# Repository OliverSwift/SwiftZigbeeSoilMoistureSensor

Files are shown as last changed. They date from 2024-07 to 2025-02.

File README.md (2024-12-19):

# Swift Zigbee Soil Moisture Sensor

This hardware project is about creating a Zigbee adapter to the existing Capacitive Soil Moisture Sensor 1.2 widely available.

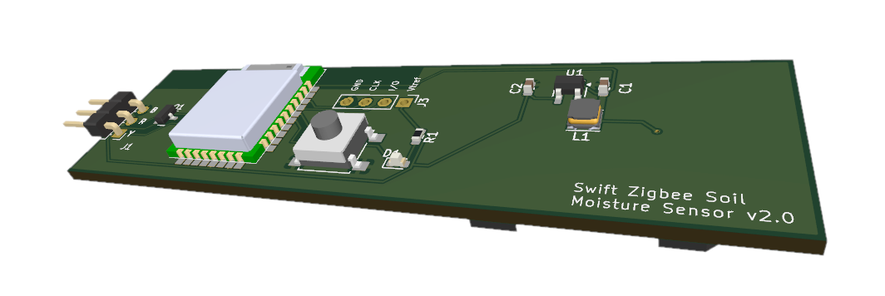
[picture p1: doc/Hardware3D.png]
Hw illustration Hardware


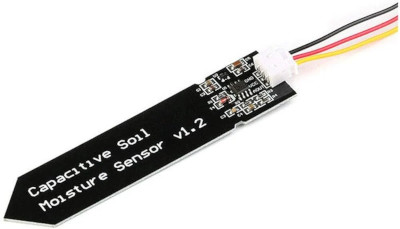
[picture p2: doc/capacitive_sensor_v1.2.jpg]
Capacitive Sensor


## How to use it

[Here is](doc/Swift%20Zigbee%20Soil%20Moisture%20Sensor.pdf) the small user manual.

It works well with Conbee2 and SONOFF zigbee concentrators used with Home Assistant.

CR2032 coin battery should allow approximately two years of autonomy.

## Technical background

After some trials on STM32WB55 which permanently failed to connect to a zigbee concentrator (Conbee2) I finally chose the nrf52840 SOC from Nordic Semicondudtors. It is very well known in the BLE world and decided to test its Zigbee capabilities and it was successful. Best solutions are provided by Texas Instrument (CC2350) and Silabs (EFR32MG1) at the moment. Using nrf52840 for Zigbee is the challenge here.

The solution is based on ZephyrOS and NRF Connect SDK version 2.6.1 that includes ZBoss proprietary Zigbee stack. One of the challenging aspect of this project is the power consumption. The nrf52840 is able to enter deep sleep and only consumes 2.5µA approximately. Now I had to face that the Capacitive Sensor is based on a NE555. Surprisingly it is not the CMOS version and is supposed to be power supplied between 5 and 15V. But it can be with only 3.3V. Any attempt to power supply below this value resulted in unstable sensor. So I decided to use 3.3V for the whole device (MCU+sensor). This led to choosing a boost converter so a coin battery can be used, ideally CR2032.

The average current measurement is about 10µA, which should allow 2 year autonomy. Probe measurement is done every 30 minutes. When it occurs, the tiny LED lits.

The project was developed thanks to [nRF52840 DK board](doc/nRF52840_DK_User_Guide_v1.2.pdf). I used the OB JLink capability to flash the target board.

The nRF52840 module (E73-2G4M08S1C) comes from EBYTE. It doesn't have the external 32kHz crystal, but this one isn't useful for Zigbee applications.

Documentation folder includes:

- [Electronic schematics](doc/schematics-2.0.pdf)
- Main components datasheet (nrf52840 and tps61097a)
- [How to build and flash](doc/how_to_compile.md)

CAD folder includes:

- [KiCAD](cad/KiCAD) project files
- [FreeCAD](cad/FreeCAD) projet, a desparate attempt to design a [box with a lid](cad/FreeCAD/box+lid.stl).

## Project details

### Building system

The ZephyrOS ecosystem provides high level build system called _west_. It's a pile of Python scripts that doesn't do much else than invoking _cmake_. I quickly realized that cmake can be used solely without the cumbersome _west_ layer. I ended up with a simple Makefile to achieve the bare necessities. 

Forgot to say that I use Linux (Ubuntu or Debian), but this should work well with MacOSX either. I struggled to make Nordic tools to run on Ubuntu 24.04 (app images need to run without sandbox), but this is definitely possible.

Before compiling, ensure to run shell that sets environment variables properly. This tiny shell can be generated by SDK Management Tool.

Building for target is building for production. Use make _clean_, _prod_ and _flash_prod_ for final hardware.

Building for developement on DK is done with a simple 'make' and 'make flash'. In this configuration, serial line is used for message printing and measurement is performed every minute (see _prj.conf_ file).

### Zigbee part

Since it's a soil moisture sensor the device exposes a standard profile from ZHA. I added the battery profile to monitor the coin battery health. These two profiles are installed in main.c file. I crafted a derived battery profile structure myself (ZB_ZCL_DECLARE_POWER_CONFIG_ATTRIB_LIST2), because the predefined ones were either thick or missing additional definitions. Some missing stuff in ZBoss library. Since these structures are built with macros, it wasn't hard to build a more suitable one.

The device is a **Sleepy End Device** (SED), so it doesn't contribute to Zigbee network activities, it just reports periodically attributes.
Low power management was actually easy to do, the nrf52840 is very convenient for this. Choose the SDK wisely, the one that actually worked well for low power is SDK 2.6.1. Older ones resulted in 700µA consumption while asleep. This was way too far from promising 2µA or so. With SDK 2.6.1 the module only consumes 2.3µA when entering deep sleep.

Setting up a SED consists in calling '_zigbee_configure_sleepy_behavior(true)_' and '_power_down_unused_ram()_' at start up. The project configuration file (prj_power_saving.conf) contains:
- CONFIG_ZIGBEE_ROLE_END_DEVICE=y
- CONFIG_RAM_POWER_DOWN_LIBRARY=y

directives for that purpose.

The most tricky part of the code lies in Zigbee event management especially when joining or leaving a network. It also deals with factory reset.

Long poll interval is adjusted to 2 minutes instead of default 7 seconds. This drastically reduces average consumption. More than 2 minutes resulted in rejoin procedure failure or reparenting failure in the mesh. That caused headaches. My opinion is that this part is the weak one of ZBoss stack (also used with ESP32 systems). That's where Silabs and Texas Instrument are still leading the Zigbee field.

### I/O

Two analog inputs are setup, one for probe and one to measure battery voltage. Due to E73 module pinout, peculiar pins were chosen so they are accessible among the castellated ones.

The probe uses 10mA to make a humidity measurement. So it is driven by a MOSFET controlled by a GPIO. The probe is therefore powered when used. A serie of measurements are done in a loop until stable.

A led is useful with embedded devices. The one on this board reflects pairing process status and measurement operation.

As mentioned, the 32kHz external crystal is not used, saving some components. It is not needed for Zigbee because clock precision isn't required here. But, it is necessary to add the two following defines in project file:
- CONFIG_CLOCK_CONTROL_NRF_K32SRC_RC=y
- CONFIG_CLOCK_CONTROL_NRF_K32SRC_XTAL=n

This tells bootloader not to use internal 32kHz clock and not to calibrate it. Otherwise MCU won't boot stuck in calibration loop.

Using the internal 32kHz clock didn't result in extra consumption.

### Hardware part

As mentionned earlier, the external probe needs at least 3.3V. The nrf52840 usually runs at 3V (usual coin battery voltage), but supports up to 3.7V. I had to find a boost IC with low quiescent current so I can use a 3V battery and power supplies the external probe. Best choice so far is a TPS 61097a from Texas Instrument (TPS 61121 worked well either, but was twice as much more expensive).

### Measurement

The measurement operation occurs every 30 minutes. This is configured in _Kconfig_ file. An hour should suffice actually and save more power.

A low filter is applied on subsequent measures. It might be too strong and should be reduced.

Illustration of using _Swift Soil Moisture Sensor_ in Home Assistant:

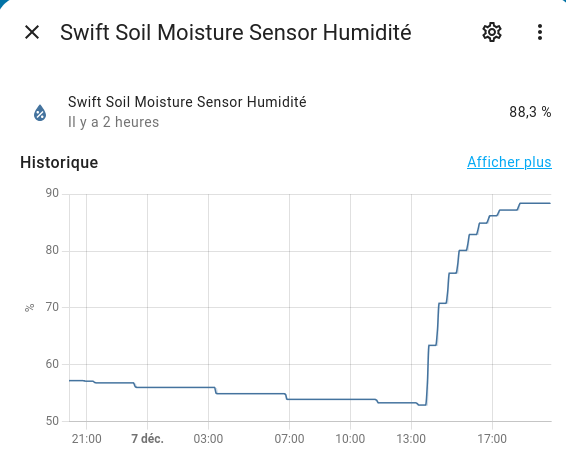
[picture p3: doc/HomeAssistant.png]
HomeAssistant


## LICENSE

SPDX-License-Identifier: AGPL-3.0-or-later

[GNU AFFERO GENERAL PUBLIC LICENSE, Version 3, 19 November 2007](LICENSE)

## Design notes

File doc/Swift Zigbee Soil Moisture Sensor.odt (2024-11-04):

Swift Zigbee Soil Moisture Sensor

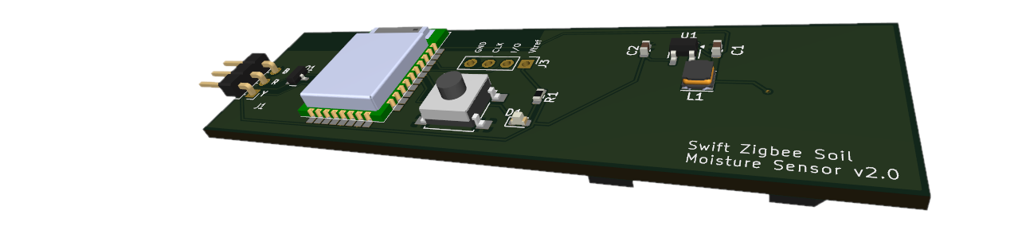
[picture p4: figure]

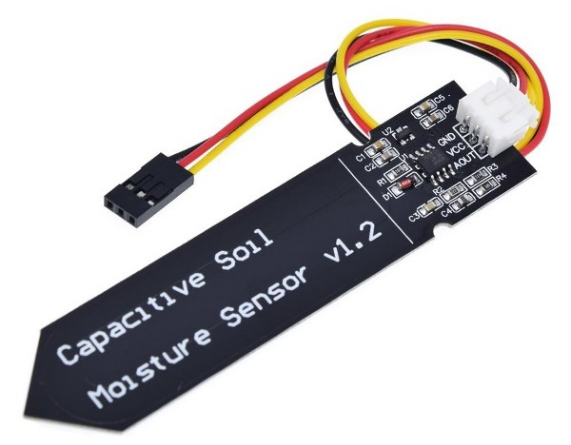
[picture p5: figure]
Capacitive soil moisture sensor V1.2 – ielectrony
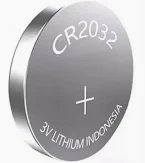
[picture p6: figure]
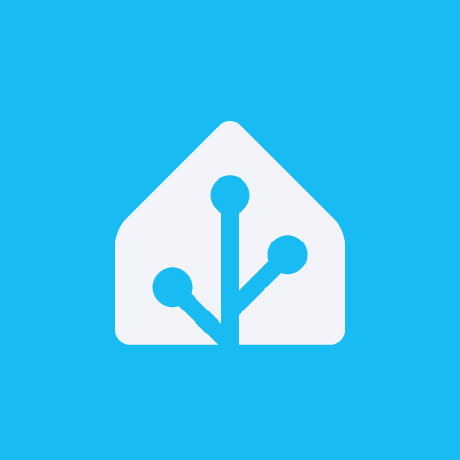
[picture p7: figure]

Needed accessories: CR2032 battery cell Capacitive Soil Moisture Sensor v1.2 Any Zigbee 3.0 ZHA compatible hub

# Prepare board

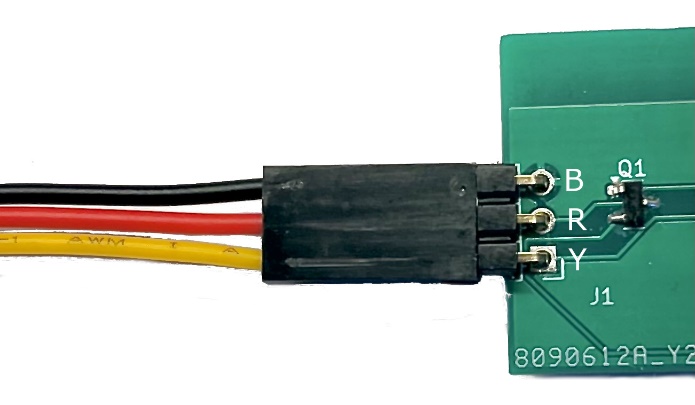
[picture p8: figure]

Connect sensor to board using its cable. The black wire must be connected to the pin B of the Zigbee adapter:

# First Pairing

Start your Zigbee Coordinator (Home Assistant for example) and launch pairing operation.

Place Zigbee board near to your coordinator device (approximately a meter away). Insert coin cell battery promptly into the battery socket located at the back of the Zigbee board.

The LED starts to blink on the Zigbee board. Twice per second. Once it has paired with coordinator LED stops blinking. It will lit every 30 minutes when measurement occurs.

Place the whole device where you want to use it.

# Factory reset

Remove coin cell battery. Press SW1 button WHILE inserting the battery back into the socket. LED will blink rapidly. Release the button. Device resets and LED starts to blink again for pairing.

# Trouble shooting

In case of values updated as “unknown” or connection loss, just remove and re-insert coin battery. Check sensor connection.

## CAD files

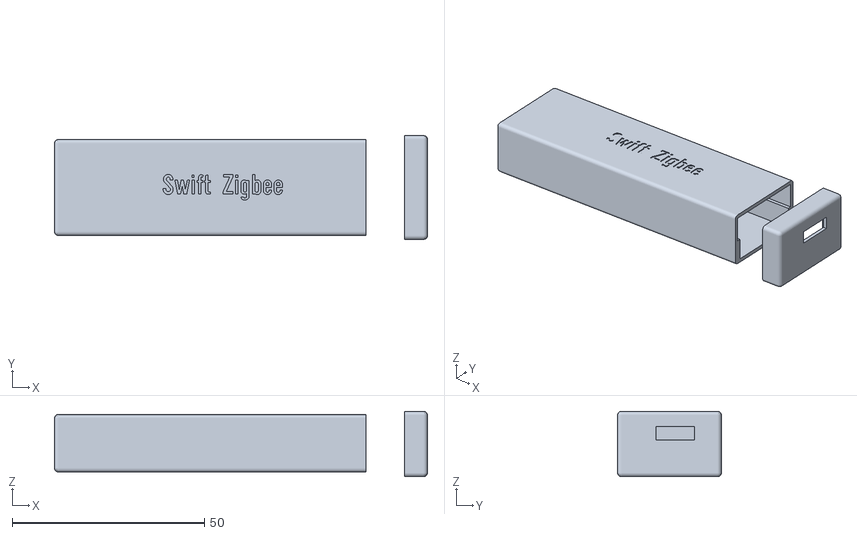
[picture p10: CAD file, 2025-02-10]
cad/FreeCAD/box+lid.stl
97.0 x 27.0 x 17.0

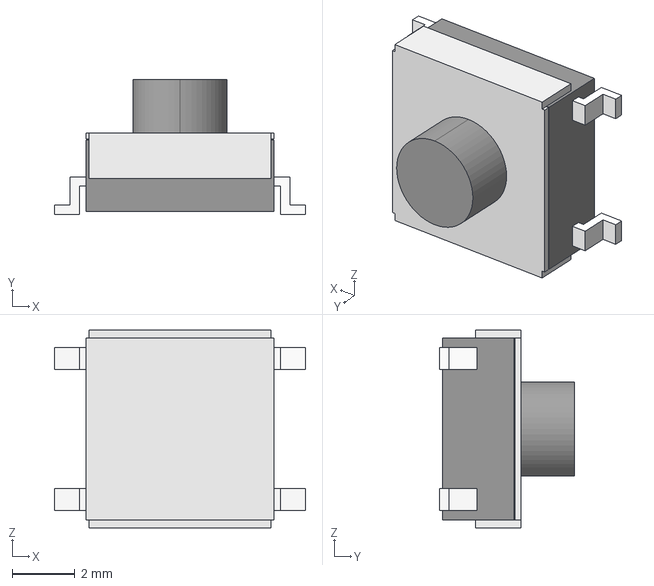
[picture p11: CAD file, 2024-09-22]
cad/KiCAD/B3FS-1010/B3FS-1010.STEP
8.00 x 4.30 x 6.30 mm

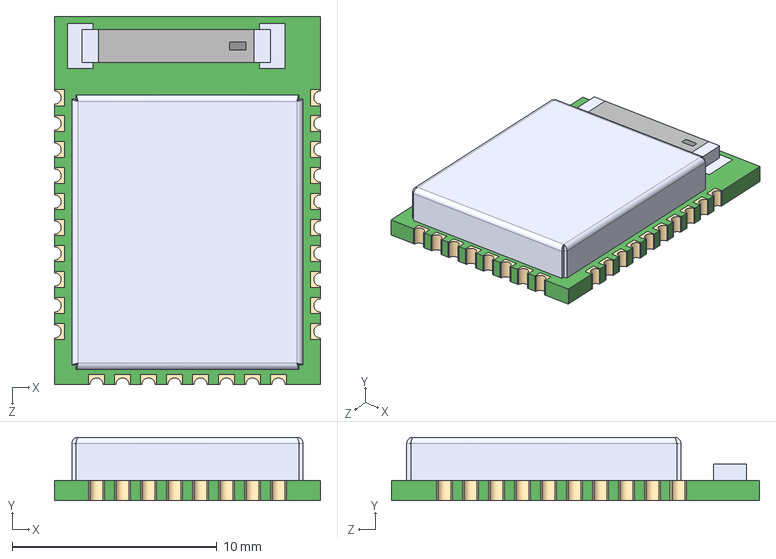
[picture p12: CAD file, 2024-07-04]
cad/KiCAD/E73-2G4M08S1C/E73-2G4M08S1C.step
13.0 x 3.10 x 18.0 mm

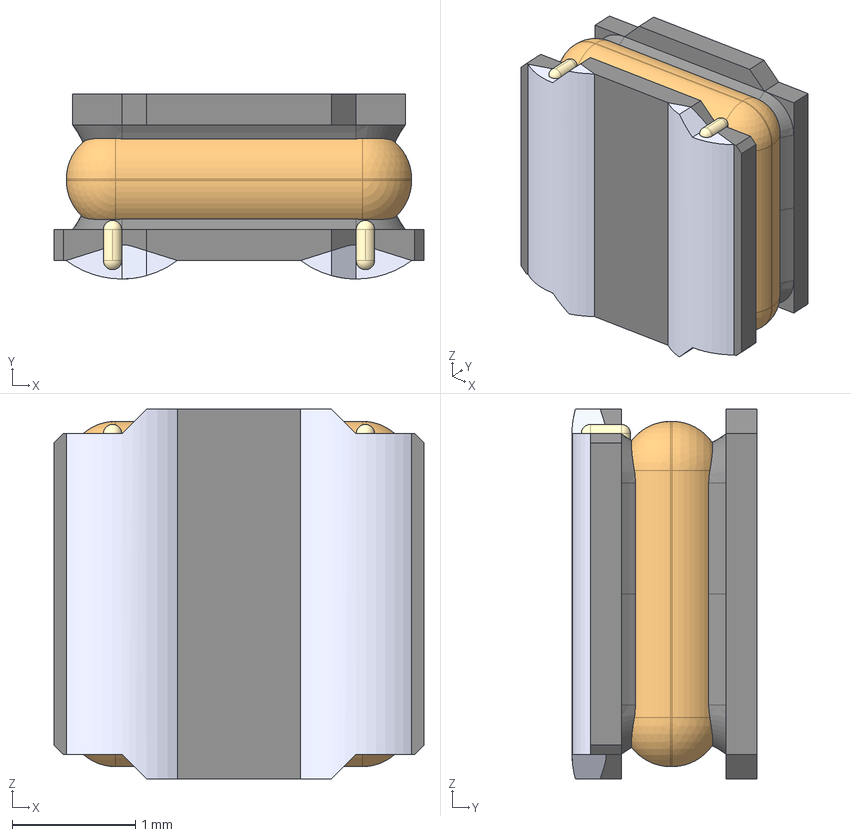
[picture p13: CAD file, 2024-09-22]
cad/KiCAD/NR3015T4R7M/NR3015T4R7M.stp
3.00 x 1.50 x 3.00 mm
NR3015T4R7M x 2
NR3015T4R7M001 x 2
NR3015T4R7M002 x 2
NR3015T4R7M003 x 2
NR3015T4R7M004 x 2
NR3015T4R7M005 x 2
NR3015T4R7M006 x 2

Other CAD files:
cad/FreeCAD/box.FCStd

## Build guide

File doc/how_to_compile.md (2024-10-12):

# With nRF Connect for Desktop
1. Get [nRF Connect for Desktop](https://www.nordicsemi.com/Products/Development-tools/nrf-connect-for-desktop)
2. Start it.
3. Install Toolchain Manager.
4. Launch Toolchain Manager (Click the Open button)
5. Install nRF Connect SDK 2.6.1 (only valid version for low power)
6. From the dropdown list select Generate Environment Script, save it to ~/ncs for example

~/ncs is where everything stands

Tools for flashing are required, see below nrf Command line Tools.

## Installing SDK Manually

Not recommanded but used SDK may not be available from nRF Connect for Desktop later on.

[Here](https://developer.nordicsemi.com/nRF_Connect_SDK/doc/latest/nrf/installation/install_ncs.html)

## Compile the project

Make sure you source the env.sh script that sets up SDK environment variables

then type:

```
# make
```

## Compile for production

```
# make clean
# make prod
```

## Nordic's page

Source pages about installations:  [SDK Installation ](https://developer.nordicsemi.com/nRF_Connect_SDK/doc/latest/nrf/installation.html)

# Installing nrfjprog for flashing

## Install nrf-Command-Line-Tools

Download [here](https://www.nordicsemi.com/Products/Development-tools/nrf-command-line-tools)

```
# dpkg -i nrf-command-line-tools_10.24.0_amd64.deb
```

Last output lines propose to install JLink that comes with the package. This is the preferred way.

## SEGGER JLink installation [optional]

Install above should propose to install JLink which is recommended.

However, it may also be installed manually:

We need to install SEGGER JLink took first. Visit [SEGGER's download page](https://www.segger.com/downloads/jlink)
And install Linux version.

```
# dpkg -i JLink_Linux_V794i_x86_64.deb
```

# Flashing the device

The board J3 connector pins have Vtref, SWDIO, SWDCLK and GND. The three should be properly wired to any SWD compatible
programming device (JLink, OB-Jlink, etc).

Cell coin battery MUST NOT be inserted during flashing operation.

## Using nrf52840 DK board for flashing

The PCA10056 comes with SEGGER J-Link OB with a debug out option.
Here is how to wire the DK to board for flashing:

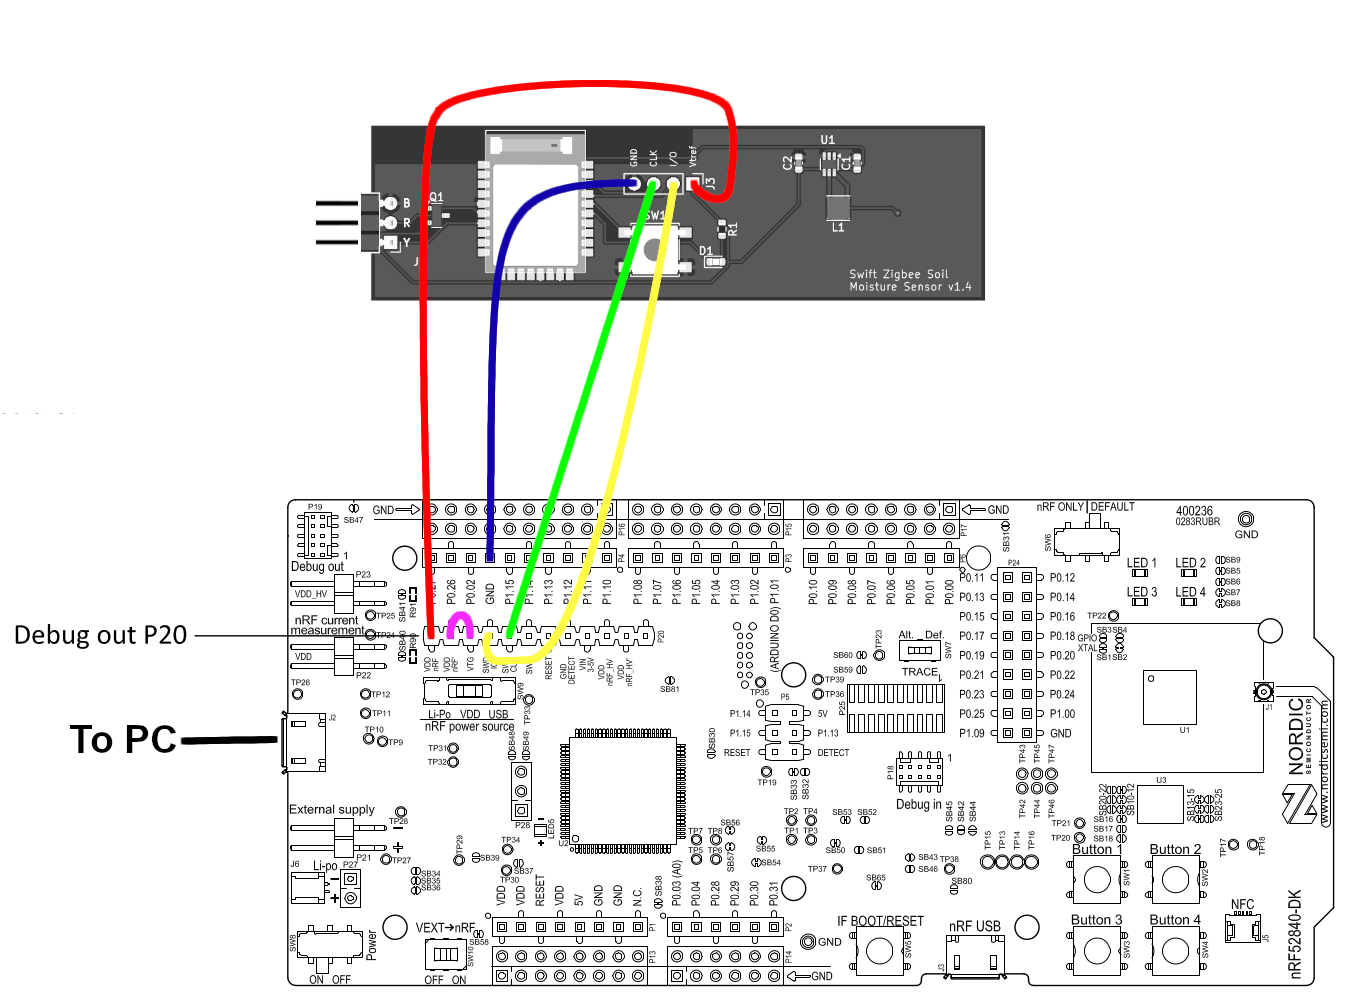
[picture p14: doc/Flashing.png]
Flashing


## Flash for dev

With JLink Probe attached to PC and board type:

```
# make flash
```

## Flash for production

Warning: AP protection is applied here. No possible debug or memory readback possible after this.

With JLink Probe attached to PC and board type:

```
# make flash_prod
```

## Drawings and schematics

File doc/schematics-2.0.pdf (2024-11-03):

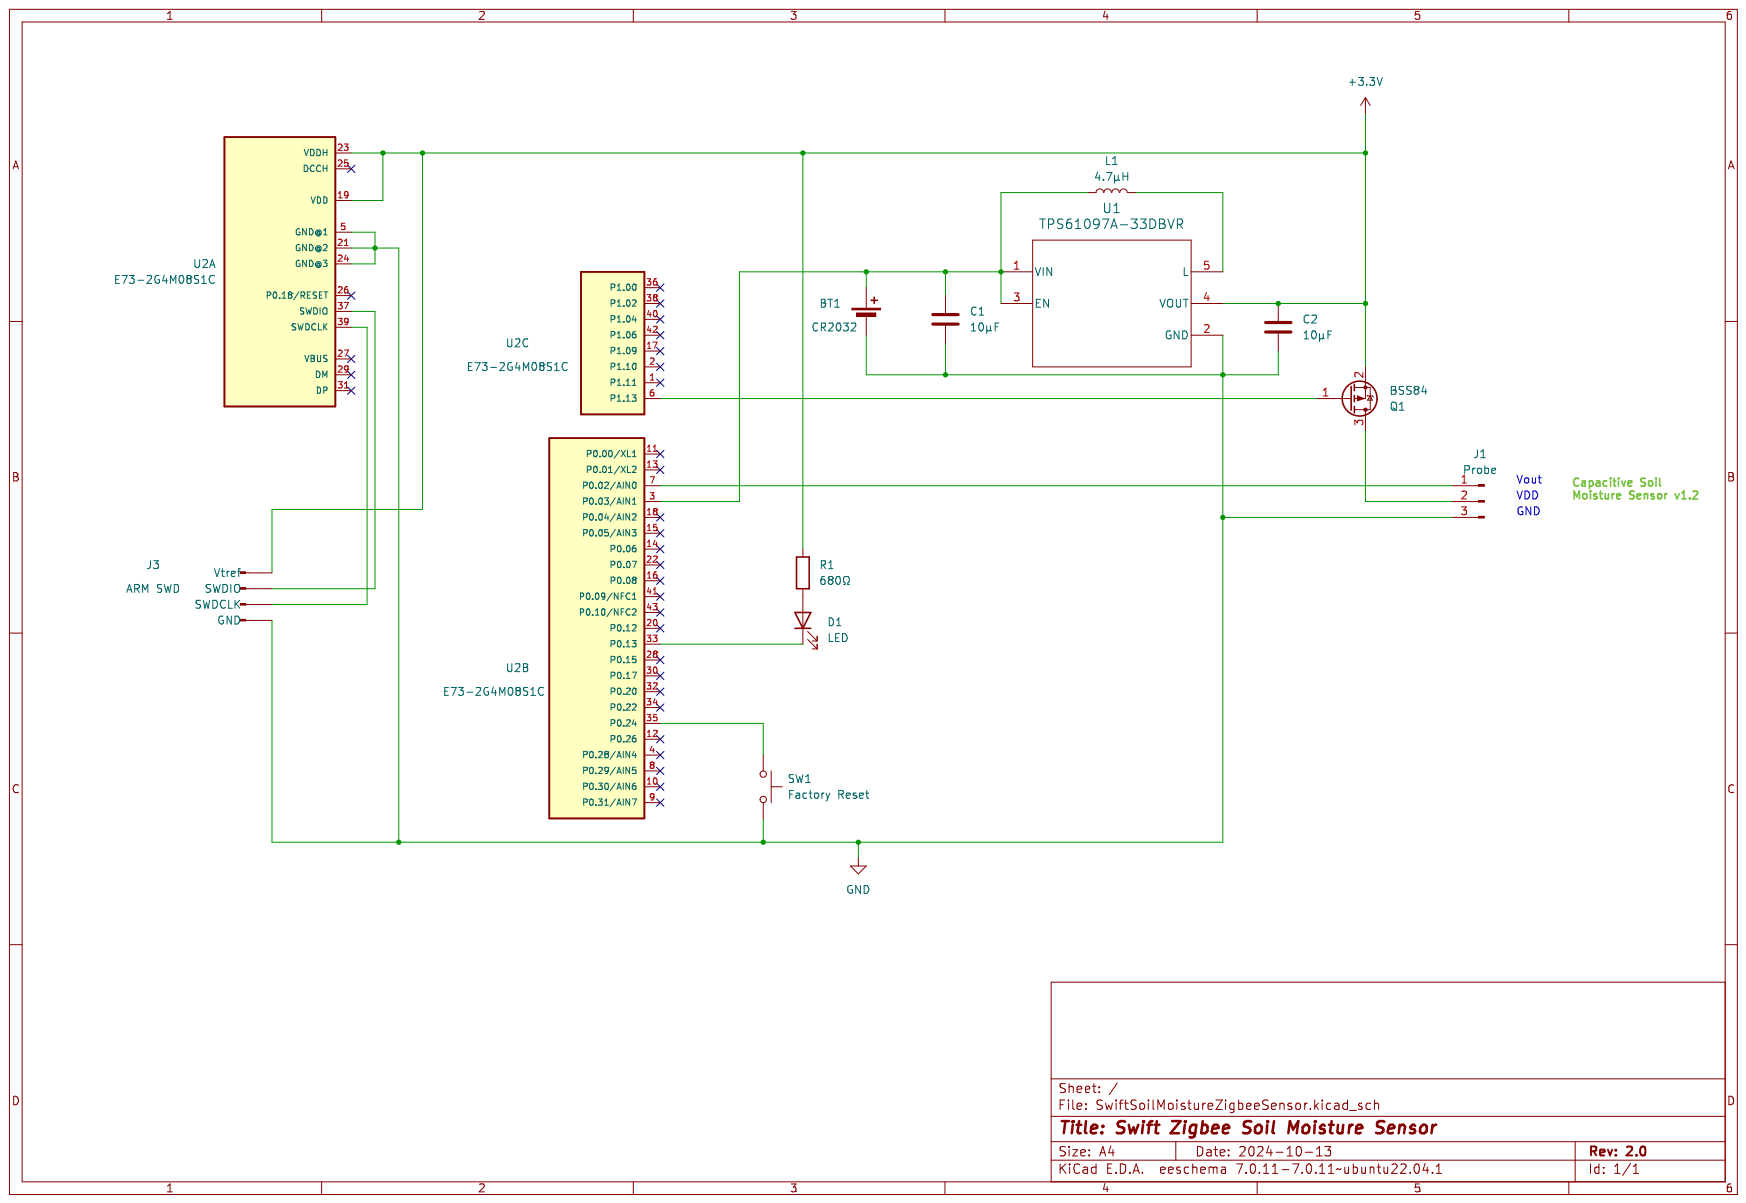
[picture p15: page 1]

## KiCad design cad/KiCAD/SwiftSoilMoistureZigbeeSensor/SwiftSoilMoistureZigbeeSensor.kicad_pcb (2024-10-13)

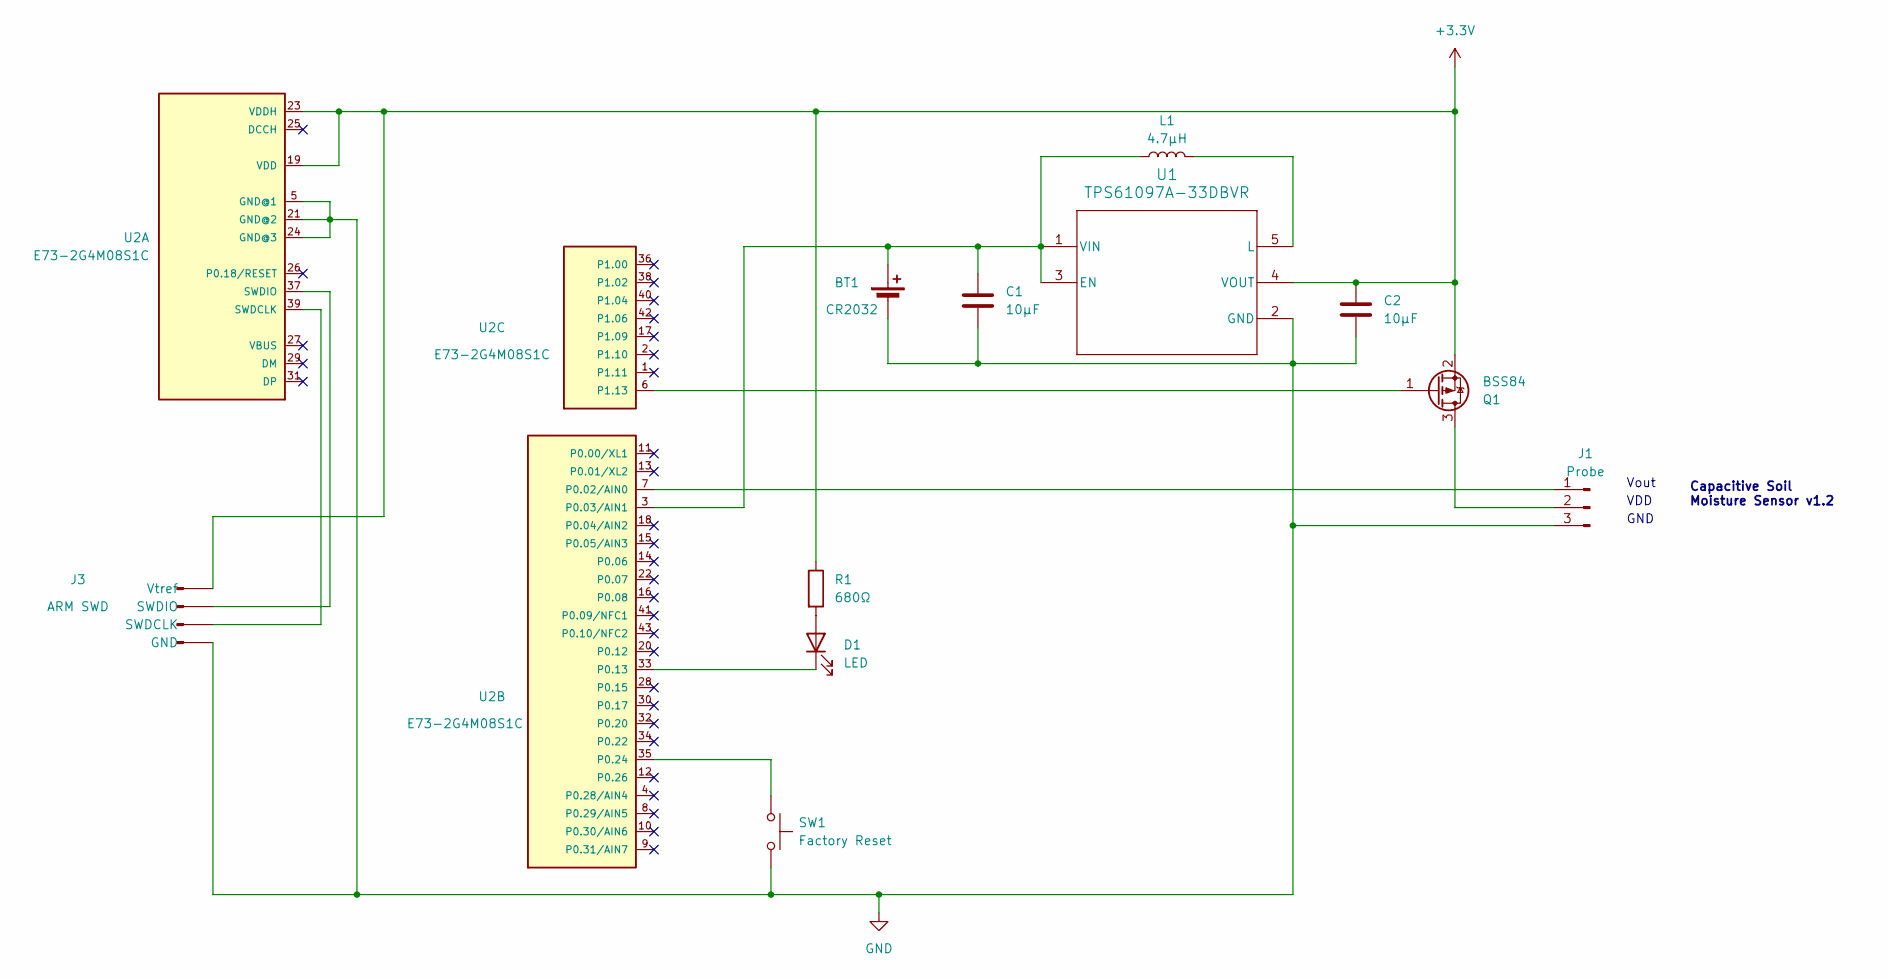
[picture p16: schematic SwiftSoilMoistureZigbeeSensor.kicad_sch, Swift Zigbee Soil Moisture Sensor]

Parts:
BT1: CR2032; BatteryHolder_Keystone_1060_1x2032; LCSC C22363833
C1, C2: 10µF; C_0603_1608Metric; LCSC C329937
D1: LED; LED_0603_1608Metric; LCSC C5246833
J1: Probe; PinHeader_1x03_P2.54mm_Horizontal; LCSC Male C2935928 / Female C7089182
J3: ARM SWD; PinHeader_1x04_P2.54mm_Vertical; LCSC C6332197
L1: 4.7µH; L_Taiyo-Yuden_NR-30xx; LCSC C87172
Q1: BSS84; SOT-23; LCSC C493579
R1: 680Ω; R_0603_1608Metric; LCSC C445820
SW1: Factory Reset; SW_SPST_B3S-1000; LCSC C231324
U1: TPS61097A-33DBVR; SOT-23-5_HandSoldering
U2: E73-2G4M08S1C; LCSC C356849

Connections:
+3.3V: C2.1, J3.1 (Vtref), Q1.2 (S), R1.1, U1.4 (VOUT), U2.19 (VDD), U2.23 (VDDH)
GND: BT1.2 (-), C1.2, C2.2, J1.3, J3.4 (GND), SW1.2, U1.2 (GND), U2.5 (GND@1), U2.21 (GND@2), U2.24 (GND@3)
unnamed: BT1.1 (+), C1.1, L1.1, U1.1 (VIN), U1.3 (EN), U2.3 (P0.03/AIN1)
unnamed: D1.2 (A), R1.2
unnamed: D1.1 (K), U2.33 (P0.13)
unnamed: J1.1, U2.7 (P0.02/AIN0)
unnamed: J1.2, Q1.3 (D)
unnamed: J3.3 (SWDCLK), U2.39 (SWDCLK)
unnamed: J3.2 (SWDIO), U2.37 (SWDIO)
unnamed: Q1.1 (G), U2.6 (P1.13)
unnamed: L1.2, U1.5 (L)
unnamed: SW1.1, U2.35 (P0.24)

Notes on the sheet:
GND
Vout
Capacitive Soil Moisture Sensor v1.2
VDD

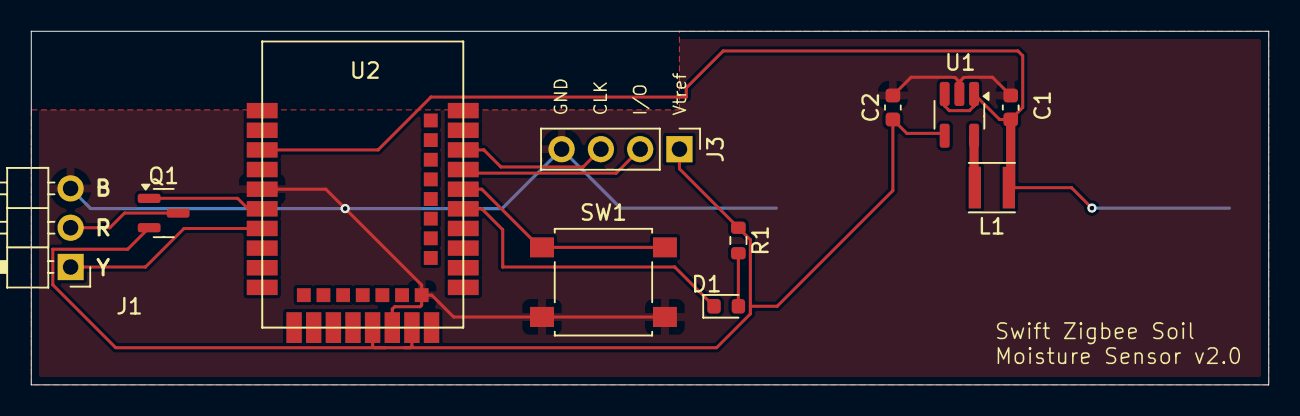
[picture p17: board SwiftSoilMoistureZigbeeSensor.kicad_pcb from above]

Board: 2 copper layers, 80.0 x 22.9 mm, 12 parts (1 on the bottom side), 12 nets.

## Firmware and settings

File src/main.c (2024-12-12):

/*
 * Copyright (c) 2021 Nordic Semiconductor ASA
 *
 * SPDX-License-Identifier: LicenseRef-Nordic-5-Clause
 */

/*
 * Copyright (c) 2024 Olivier DEBON
 *
 * Modifications on Nordic examples for this application
 * SPDX-License-Identifier: AGPL-3.0-or-later
 */

/** @file
 *
 * @brief Zigbee application swift.
 */

#include <zephyr/kernel.h>
#include <zephyr/logging/log.h>
#include <zephyr/drivers/gpio.h>
#include <zephyr/sys/reboot.h>
#include <dk_buttons_and_leds.h>
#include <ram_pwrdn.h>

#include <stdlib.h>
#include <zboss_api.h>
#include <zboss_api_addons.h>
#include <zigbee/zigbee_error_handler.h>
#include <zigbee/zigbee_app_utils.h>
#include <zb_nrf_platform.h>
#include "zb_swift_device.h"
#include "adc.h"

static const struct gpio_dt_spec probe_vdd = GPIO_DT_SPEC_GET(DT_NODELABEL(probe_vdd), gpios);

/* Device endpoint, used to receive ZCL commands. */
#define APP_SWIFT_ENDPOINT               10

/* Type of power sources available for the device.
 * For possible values see section 3.2.2.2.8 of ZCL specification.
 */
#define SWIFT_INIT_BASIC_POWER_SOURCE    ZB_ZCL_BASIC_POWER_SOURCE_BATTERY

/* LED indicating that device successfully joined Zigbee network. */
#define ZIGBEE_NETWORK_STATE_LED            DK_LED1

/* Probe measurement interval */
#define PROBE_INTERVAL_MS (CONFIG_PROBE_INTERVAL*1000)

LOG_MODULE_REGISTER(app, LOG_LEVEL_INF);

/* Main application customizable context.
 * Stores all settings and static values.
 */
struct zb_device_ctx {
	zb_zcl_basic_attrs_ext_t basic_attr;
	zb_zcl_power_config_attrs_t power_config_attr;
	zb_zcl_rel_humidity_attrs_t rel_humidity_attr;
};

/* Zigbee device application context storage. */
static struct zb_device_ctx dev_ctx;

ZB_ZCL_DECLARE_BASIC_ATTRIB_LIST_EXT(
	basic_attr_list,
	&dev_ctx.basic_attr.zcl_version,
	&dev_ctx.basic_attr.app_version,
	&dev_ctx.basic_attr.stack_version,
	&dev_ctx.basic_attr.hw_version,
	dev_ctx.basic_attr.mf_name,
	dev_ctx.basic_attr.model_id,
	dev_ctx.basic_attr.date_code,
	&dev_ctx.basic_attr.power_source,
	dev_ctx.basic_attr.location_id,
	&dev_ctx.basic_attr.ph_env,
	dev_ctx.basic_attr.sw_ver);

ZB_ZCL_DECLARE_REL_HUMIDITY_MEASUREMENT_ATTRIB_LIST(
	rel_humidity_attr_list,
	&dev_ctx.rel_humidity_attr.value,
	&dev_ctx.rel_humidity_attr.min_value,
	&dev_ctx.rel_humidity_attr.max_value
);

ZB_ZCL_DECLARE_POWER_CONFIG_ATTRIB_LIST2(
	power_config_attr_list,
	&dev_ctx.power_config_attr.voltage,
	&dev_ctx.power_config_attr.percentage_remaining,
	&dev_ctx.power_config_attr.alarm_state
);

ZB_DECLARE_SWIFT_DEVICE_CLUSTER_LIST(app_swift_clusters, basic_attr_list, power_config_attr_list, rel_humidity_attr_list);

ZB_DECLARE_SWIFT_DEVICE_EP(
	app_swift_ep,
	APP_SWIFT_ENDPOINT,
	app_swift_clusters);

ZBOSS_DECLARE_DEVICE_CTX_1_EP(
	app_swift_ctx,
	app_swift_ep);

/* Manufacturer name (32 bytes). */
#define SWIFT_INIT_BASIC_MANUF_NAME      "Swift"

/* Model number assigned by manufacturer (32-bytes long string). */
#define SWIFT_INIT_BASIC_MODEL_ID        "Soil Moisture Sensor"

/* Functions */
void do_battery_measurement();
void do_humidity_measurement(zb_uint8_t param);
void check_join_status(zb_uint8_t param);

/**@brief Function for initializing all clusters attributes. */
static void app_clusters_attr_init(void)
{
	/* Basic cluster attributes data */
	dev_ctx.basic_attr.zcl_version = ZB_ZCL_VERSION;
	dev_ctx.basic_attr.power_source = SWIFT_INIT_BASIC_POWER_SOURCE;

	ZB_ZCL_SET_STRING_VAL(
		dev_ctx.basic_attr.mf_name,
		SWIFT_INIT_BASIC_MANUF_NAME,
		ZB_ZCL_STRING_CONST_SIZE(SWIFT_INIT_BASIC_MANUF_NAME));

	ZB_ZCL_SET_STRING_VAL(
		dev_ctx.basic_attr.model_id,
		SWIFT_INIT_BASIC_MODEL_ID,
		ZB_ZCL_STRING_CONST_SIZE(SWIFT_INIT_BASIC_MODEL_ID));

	/* Power Config attributes data. */
	dev_ctx.power_config_attr.voltage = ZB_ZCL_POWER_CONFIG_BATTERY_VOLTAGE_INVALID;

	do_battery_measurement();

	/* Relative Humidity cluster attributes data. */
	dev_ctx.rel_humidity_attr.value = ZB_ZCL_ATTR_REL_HUMIDITY_MEASUREMENT_VALUE_UNKNOWN;
	dev_ctx.rel_humidity_attr.min_value = ZB_ZCL_ATTR_REL_HUMIDITY_MEASUREMENT_MIN_VALUE_MIN_VALUE;
	dev_ctx.rel_humidity_attr.max_value = ZB_ZCL_ATTR_REL_HUMIDITY_MEASUREMENT_MIN_VALUE_MAX_VALUE;

	ZB_ZCL_SET_ATTRIBUTE(
		APP_SWIFT_ENDPOINT,
		ZB_ZCL_CLUSTER_ID_REL_HUMIDITY_MEASUREMENT,
		ZB_ZCL_CLUSTER_SERVER_ROLE,
		ZB_ZCL_ATTR_REL_HUMIDITY_MEASUREMENT_VALUE_ID,
		(zb_uint8_t *)&dev_ctx.rel_humidity_attr.value,
		ZB_FALSE);

	ZB_ZCL_SET_ATTRIBUTE(
		APP_SWIFT_ENDPOINT,
		ZB_ZCL_CLUSTER_ID_REL_HUMIDITY_MEASUREMENT,
		ZB_ZCL_CLUSTER_SERVER_ROLE,
		ZB_ZCL_ATTR_REL_HUMIDITY_MEASUREMENT_MIN_VALUE_ID,
		(zb_uint8_t *)&dev_ctx.rel_humidity_attr.min_value,
		ZB_FALSE);

	ZB_ZCL_SET_ATTRIBUTE(
		APP_SWIFT_ENDPOINT,
		ZB_ZCL_CLUSTER_ID_REL_HUMIDITY_MEASUREMENT,
		ZB_ZCL_CLUSTER_SERVER_ROLE,
		ZB_ZCL_ATTR_REL_HUMIDITY_MEASUREMENT_MAX_VALUE_ID,
		(zb_uint8_t *)&dev_ctx.rel_humidity_attr.max_value,
		ZB_FALSE);

	// Modify min reporting interval period
	zb_zcl_reporting_info_t *rep_info;

	rep_info = zb_zcl_find_reporting_info(APP_SWIFT_ENDPOINT, ZB_ZCL_CLUSTER_ID_REL_HUMIDITY_MEASUREMENT, ZB_ZCL_CLUSTER_SERVER_ROLE, ZB_ZCL_ATTR_REL_HUMIDITY_MEASUREMENT_VALUE_ID);

	if (rep_info) {
	    rep_info->u.send_info.def_min_interval = PROBE_INTERVAL_MS/1000;
	    rep_info->u.send_info.def_max_interval = 7200; // 2 hours
	} else {
	    LOG_ERR("Can't find HUMIDITY attribute");
	}

	rep_info = zb_zcl_find_reporting_info(APP_SWIFT_ENDPOINT, ZB_ZCL_CLUSTER_ID_POWER_CONFIG, ZB_ZCL_CLUSTER_SERVER_ROLE, ZB_ZCL_ATTR_POWER_CONFIG_BATTERY_PERCENTAGE_REMAINING_ID);

	if (rep_info) {
	    rep_info->u.send_info.def_min_interval = PROBE_INTERVAL_MS/1000;
	    rep_info->u.send_info.def_max_interval = 7200; // 2 hours
	} else {
	    LOG_ERR("Can't find POWER CONFIG attribute");
	}

	/* Install reporting */
	if (RET_OK != zb_zcl_start_attr_reporting(APP_SWIFT_ENDPOINT,
						  ZB_ZCL_CLUSTER_ID_REL_HUMIDITY_MEASUREMENT,
						  ZB_ZCL_CLUSTER_SERVER_ROLE,
						  ZB_ZCL_ATTR_REL_HUMIDITY_MEASUREMENT_VALUE_ID)) {
	    LOG_INF("Failed to start Attribute reporting");
	}

	if (RET_OK != zb_zcl_start_attr_reporting(APP_SWIFT_ENDPOINT,
						  ZB_ZCL_CLUSTER_ID_POWER_CONFIG,
						  ZB_ZCL_CLUSTER_SERVER_ROLE,
						  ZB_ZCL_ATTR_POWER_CONFIG_BATTERY_PERCENTAGE_REMAINING_ID)) {
	    LOG_INF("Failed to start Attribute reporting");
	}
}

/**@brief Function for initializing LEDs and Buttons. */
static void configure_gpio(void)
{
	int err;

	err = dk_buttons_init(NULL);
	if (err) {
		LOG_ERR("Cannot init buttons (err: %d)", err);
	}

	err = dk_leds_init();
	if (err) {
		LOG_ERR("Cannot init LEDs (err: %d)", err);
	}

	if (!gpio_is_ready_dt(&probe_vdd)) {
	    LOG_ERR("Can't get GPIO1.15 ready");
	} else
	if (gpio_pin_configure_dt(&probe_vdd, GPIO_OUTPUT_INACTIVE) < 0) {
	    LOG_ERR("Can't configure GPIO1.15");
	}
}

/**@brief Callback function for handling ZCL commands.
 *
 * @param[in]   bufid   Reference to Zigbee stack buffer
 *                      used to pass received data.
 */
static void zcl_device_cb(zb_bufid_t bufid)
{
	zb_zcl_device_callback_param_t  *device_cb_param =
		ZB_BUF_GET_PARAM(bufid, zb_zcl_device_callback_param_t);

	LOG_INF("%s id %hd", __func__, device_cb_param->device_cb_id);

	/* Set default response value. */
	device_cb_param->status = RET_OK;

	switch (device_cb_param->device_cb_id) {
	default:
		device_cb_param->status = RET_NOT_IMPLEMENTED;
		break;
	}

	LOG_INF("%s status: %hd", __func__, device_cb_param->status);
}

static bool joined = false;
static bool first_start = false;

/**@brief Zigbee stack event handler.
 *
 * @param[in]   bufid   Reference to the Zigbee stack buffer
 *                      used to pass signal.
 */
void zboss_signal_handler(zb_bufid_t bufid)
{
    zb_zdo_app_signal_hdr_t * p_sg_p = NULL;
    zb_zdo_app_signal_type_t sig = zb_get_app_signal(bufid, &p_sg_p);
    zb_ret_t status = ZB_GET_APP_SIGNAL_STATUS(bufid);

    switch (sig) {
    case ZB_BDB_SIGNAL_DEVICE_FIRST_START:
	first_start = true;
	ZB_ERROR_CHECK(zigbee_default_signal_handler(bufid));
	break;
    case ZB_BDB_SIGNAL_DEVICE_REBOOT:
    case ZB_BDB_SIGNAL_STEERING:
	if (status == RET_OK) {
	    LOG_INF("Joined network successfully");
	    /* Change long poll interval once device has joined */
	    zb_zdo_pim_set_long_poll_interval(120*1000); // 2 minutes should be enough

	    joined = true;
	} else {
	    joined = false;
	}
	ZB_ERROR_CHECK(zigbee_default_signal_handler(bufid));
	break;
    case ZB_ZDO_SIGNAL_LEAVE:
	// Wait until Factory reset is released, then RESET
	// Meanwhile fast LED blinking
	while(dk_get_buttons() & DK_BTN3_MSK) {
	    dk_set_led(ZIGBEE_NETWORK_STATE_LED, 0);
	    k_msleep(50);
	    dk_set_led(ZIGBEE_NETWORK_STATE_LED, 1);
	    k_msleep(50);
	}
	sys_reboot(SYS_REBOOT_COLD);
	break;
    case ZB_ZDO_SIGNAL_SKIP_STARTUP:
	if (zigbee_is_stack_started() && (!zb_bdb_is_factory_new()) && (dk_get_buttons() & DK_BTN3_MSK)) {
	    LOG_INF("FACTORY RESET BUTTON pressed at start up - Scheduling Factory Reset");
	    ZB_SCHEDULE_APP_CALLBACK(zb_bdb_reset_via_local_action, 0);
	    break;
	}
	// Fallthru
    default:
	// Call default signal handler.
	ZB_ERROR_CHECK(zigbee_default_signal_handler(bufid));
	break;
    }


    /* All callbacks should either reuse or free passed buffers.
    * If bufid == 0, the buffer is invalid (not passed).
    */
    if (bufid) {
	zb_buf_free(bufid);
    }

}

#define BATTERY_HIGH_100MV 28
#define BATTERY_LOW_100MV 16

void do_battery_measurement() {
	uint8_t battery_voltage;

	battery_voltage = adc_battery(); // 100mv per unit

	if (dev_ctx.power_config_attr.voltage != ZB_ZCL_POWER_CONFIG_BATTERY_VOLTAGE_INVALID) {
	    // Low filter
	    battery_voltage = (uint8_t)(((uint16_t)dev_ctx.power_config_attr.voltage * 3 + (uint16_t)battery_voltage + 2)/4);
	}

	dev_ctx.power_config_attr.voltage = battery_voltage;

	if (battery_voltage > BATTERY_HIGH_100MV) {
	    dev_ctx.power_config_attr.percentage_remaining = 200; // 200 half percent
	} else if (battery_voltage < BATTERY_LOW_100MV) {
	    dev_ctx.power_config_attr.percentage_remaining = 0;
	} else {
	    dev_ctx.power_config_attr.percentage_remaining = (battery_voltage-BATTERY_LOW_100MV)*200/(BATTERY_HIGH_100MV-BATTERY_LOW_100MV);
	}

	LOG_INF("Battery voltage (capacity): %d mv (%d%%)", battery_voltage*100, dev_ctx.power_config_attr.percentage_remaining/2);

	ZB_ZCL_SET_ATTRIBUTE(
		APP_SWIFT_ENDPOINT,
		ZB_ZCL_CLUSTER_ID_POWER_CONFIG,
		ZB_ZCL_CLUSTER_SERVER_ROLE,
		ZB_ZCL_ATTR_POWER_CONFIG_BATTERY_VOLTAGE_ID,
		(zb_uint8_t *)&dev_ctx.power_config_attr.voltage,
		ZB_FALSE);

	ZB_ZCL_SET_ATTRIBUTE(
		APP_SWIFT_ENDPOINT,
		ZB_ZCL_CLUSTER_ID_POWER_CONFIG,
		ZB_ZCL_CLUSTER_SERVER_ROLE,
		ZB_ZCL_ATTR_POWER_CONFIG_BATTERY_PERCENTAGE_REMAINING_ID,
		(zb_uint8_t *)&dev_ctx.power_config_attr.percentage_remaining,
		ZB_FALSE);
}

void do_humidity_measurement(zb_uint8_t param) {
#ifdef VDD_3V
    // These comes from Capacitive Soil Moisture Sensor v1.2 powered by 3.0V
#pragma message("Probe supply 3V")
#define MIN_MV 450
#define MAX_MV 1825
#else
    // These come from Capacitive Soil Moisture Sensor v1.2 powered by 3.3V
#define MIN_MV 910
#define MAX_MV 2160
#endif

#define PROBE_POWERUP_TIME_MS 1000
#define COUNTDOWN_INIT (4*3600*1000/PROBE_INTERVAL_MS)

	int32_t val_mv;
	uint16_t humidity; // 100 x H%
	static uint16_t humidity_last = 0xffff;
	static uint32_t force_report_countdown = COUNTDOWN_INIT; // When falling to 0, 4 hours, force reporting

	dk_set_led(ZIGBEE_NETWORK_STATE_LED, 1);

	// Power on the probe
	gpio_pin_set_dt(&probe_vdd,1);
	k_msleep(PROBE_POWERUP_TIME_MS); // Wait for output to stabilize

	// Measurement
	// Found out that multiple measurements must be done. Either probe or adapter hardware are not reliable.
	// Here we measure voltage every 100ms, if two subsequent values difference is less than 100mV, measurement
	// is considered stable. At most 10 times in a row.
	val_mv = adc_probe();
	k_msleep(100);
	for(int t = 0; t < 10; t++) {
	    int32_t val = val_mv;
	    val_mv = adc_probe();
	    if (abs(val-val_mv) <= 100) break;
	    k_msleep(100);
	}

	dk_set_led(ZIGBEE_NETWORK_STATE_LED, 0);

	// Power off the probe
	gpio_pin_set_dt(&probe_vdd,0);

	if (val_mv < MIN_MV) {
	    humidity = 100; // Max humidity
	} else if (val_mv > MAX_MV) {
	    humidity = 0; // Min humidity
	} else {
	    // MIN_MV => 100% (water)
	    // MAX_MV => 0% (air)
	    humidity = 100-((val_mv - MIN_MV)*100/(MAX_MV-MIN_MV));
	}

	humidity *= 100;

	// Low filter
	if (humidity_last != 0xffff) {
	    humidity = (humidity_last*3 + humidity +2)/4;
	}

	LOG_INF("Mean %dmv -> Humidity %d [%d]", val_mv, humidity, humidity_last);

	if (humidity/100 != humidity_last/100 || (force_report_countdown-- == 0)) {
	    force_report_countdown = COUNTDOWN_INIT;

	    do_battery_measurement(); // Take opportunity to update battery health

	    dev_ctx.rel_humidity_attr.value = (humidity/10)*10; // Rounding at 10th

	    ZB_ZCL_SET_ATTRIBUTE(
		    APP_SWIFT_ENDPOINT,
		    ZB_ZCL_CLUSTER_ID_REL_HUMIDITY_MEASUREMENT,
		    ZB_ZCL_CLUSTER_SERVER_ROLE,
		    ZB_ZCL_ATTR_REL_HUMIDITY_MEASUREMENT_VALUE_ID,
		    (zb_uint8_t *)&dev_ctx.rel_humidity_attr.value,
		    ZB_FALSE);

	    LOG_INF("Updating humidity value: %d%%", humidity/100);
	}

	humidity_last = humidity;

	if (first_start) {
	    ZB_SCHEDULE_APP_ALARM(do_humidity_measurement, 0, ZB_MILLISECONDS_TO_BEACON_INTERVAL(15000)); // Shorten delay of next measurement
	    first_start = false;
	    force_report_countdown = 0; // Ugly, but this will force report on next call
	} else {
	    ZB_SCHEDULE_APP_ALARM(do_humidity_measurement, 0, ZB_MILLISECONDS_TO_BEACON_INTERVAL(PROBE_INTERVAL_MS));
	}
}

#define NETWORK_LED_PERIOD_MS 200

void check_join_status(zb_uint8_t param) {
    static uint8_t led_state = 1;

    if (joined) {
	// Light off LED and start measurements
	dk_set_led(ZIGBEE_NETWORK_STATE_LED, 0);
	do_humidity_measurement(0);
	return;
    }

    led_state ^= 1;

    dk_set_led(ZIGBEE_NETWORK_STATE_LED, led_state);

    ZB_SCHEDULE_APP_ALARM(check_join_status, 0, ZB_MILLISECONDS_TO_BEACON_INTERVAL(NETWORK_LED_PERIOD_MS));
}

int main(void)
{
	LOG_INF("Starting ADC reading on AIN0 and AIN1");
	adc_setup();

	LOG_INF("Starting Zigbee application swift example");

	/* Initialize */
	configure_gpio();

	/* Set Led on at startup */
	dk_set_led(ZIGBEE_NETWORK_STATE_LED, 1);

	/* Register callback for handling ZCL commands. */
	ZB_ZCL_REGISTER_DEVICE_CB(zcl_device_cb);

	/* Register device context (endpoints). */
	ZB_AF_REGISTER_DEVICE_CTX(&app_swift_ctx);

	app_clusters_attr_init();

	/* Set Sleepy End Device mode */
	zigbee_configure_sleepy_behavior(true);

	zb_set_ed_timeout(ED_AGING_TIMEOUT_256MIN);

	/* Save power */
#if CONFIG_RAM_POWER_DOWN_LIBRARY == 1
	power_down_unused_ram();
#endif

	/* Start Zigbee default thread */
	zigbee_enable();

	LOG_INF("Zigbee application swift started");

	ZB_SCHEDULE_APP_ALARM(check_join_status, 0, ZB_MILLISECONDS_TO_BEACON_INTERVAL(NETWORK_LED_PERIOD_MS));

	return 0;
}

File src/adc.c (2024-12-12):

/*
 * Copyright (c) 2020 Libre Solar Technologies GmbH
 *
 * SPDX-License-Identifier: Apache-2.0
 */

/*
 * Copyright (c) 2024 Olivier DEBON
 *
 * Modifications on Nordic examples for this application
 * SPDX-License-Identifier: AGPL-3.0-or-later
 */

#include <inttypes.h>
#include <stddef.h>
#include <stdint.h>

#include <zephyr/device.h>
#include <zephyr/devicetree.h>
#include <zephyr/drivers/adc.h>
#include <zephyr/kernel.h>
#include <zephyr/logging/log.h>

LOG_MODULE_REGISTER(adc, LOG_LEVEL_INF);

#if !DT_NODE_EXISTS(DT_PATH(zephyr_user)) || \
	!DT_NODE_HAS_PROP(DT_PATH(zephyr_user), io_channels)
#error "No suitable devicetree overlay specified"
#endif

#define DT_SPEC_AND_COMMA(node_id, prop, idx) \
	ADC_DT_SPEC_GET_BY_IDX(node_id, idx),

/* Data of ADC io-channels specified in devicetree. */
static const struct adc_dt_spec adc_channels[] = {
	DT_FOREACH_PROP_ELEM(DT_PATH(zephyr_user), io_channels,
			     DT_SPEC_AND_COMMA)
};

int adc_setup(void)
{
	int err;

	/* Configure channel 0 prior to sampling. */
	if (!device_is_ready(adc_channels[0].dev)) {
		LOG_ERR("ADC controller device %s not ready\n", adc_channels[0].dev->name);
		return 0;
	}

	err = adc_channel_setup_dt(&adc_channels[0]);
	if (err < 0) {
		LOG_ERR("Could not setup channel 0 (%d)\n", err);
		return 0;
	}

	/* Configure channel 1 prior to sampling. */
	if (!device_is_ready(adc_channels[1].dev)) {
		LOG_ERR("ADC controller device %s not ready\n", adc_channels[1].dev->name);
		return 0;
	}

	err = adc_channel_setup_dt(&adc_channels[1]);
	if (err < 0) {
		LOG_ERR("Could not setup channel 1 (%d)\n", err);
		return 0;
	}

	return 1; // Ok
}

int32_t adc_probe()
{
	int err;
	uint16_t buf;
	struct adc_sequence sequence = {
		.buffer = &buf,
		/* buffer size in bytes, not number of samples */
		.buffer_size = sizeof(buf),
	};
	int32_t val_mv;

	(void)adc_sequence_init_dt(&adc_channels[0], &sequence);

	err = adc_read(adc_channels[0].dev, &sequence);
	if (err < 0) {
		LOG_ERR("Could not read (%d)\n", err);
		return -1;
	}

	val_mv = (int32_t)((int16_t)buf);

	err = adc_raw_to_millivolts_dt(&adc_channels[0], &val_mv);

	LOG_INF("- %s, channel %d: %"PRId32" mV", adc_channels[0].dev->name, adc_channels[0].channel_id, val_mv);

	return val_mv;
}

uint8_t adc_battery()
{
	int err;
	uint16_t buf;
	struct adc_sequence sequence = {
		.buffer = &buf,
		/* buffer size in bytes, not number of samples */
		.buffer_size = sizeof(buf),
	};
	int32_t val_mv;

	(void)adc_sequence_init_dt(&adc_channels[1], &sequence);

	err = adc_read(adc_channels[1].dev, &sequence);
	if (err < 0) {
		LOG_ERR("Could not read (%d)\n", err);
		return -1;
	}

	val_mv = (int32_t)((int16_t)buf);

	err = adc_raw_to_millivolts_dt(&adc_channels[0], &val_mv);

	LOG_INF("- %s, channel %d: %"PRId32" mV", adc_channels[1].dev->name, adc_channels[1].channel_id, val_mv);

	return (uint8_t)(val_mv/100);
}

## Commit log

2023-08-04 First Zigbee Switch with nrf52840 dongle
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2023-08-06 Integrated ADC code to read Analog AIN0 (pin P0.02)
2023-08-06 Signed reading from ADC in mV
2023-08-23 1 minute min report intervale. Bug with last value
    [main.c]
2023-08-25 Removed external LFXO 32768Hz XTAL. Use internal RC clock
2023-08-25 Probe internal define, set to 1 minute. Low filter on subsequent measurements
2023-08-25 Changed variable range (bug)
    [main.c]
2023-08-25 Power the probe though PIN1.15
2023-08-25 Can't drive probe with GPIO, need a MOSFET
2023-08-26 Cleaner probe actions
    Reactivated P1.15 probe command.
    Check after minimum voltage and warn if needed
    60 secs periodic probe measurement.
2023-09-03 Changed low filter and rounding value
2023-09-08 Low filter on ADC values
2023-09-16 Added power saving config
2023-09-17 Make led blink until joined
2023-09-17 Driving P-MOS so active pin is Low
2023-09-22 DK schematics added to doc
2023-10-15 Moved led set after state computation update. Minor
2023-10-15 Shortened probe power supply time
    [main.c]
2023-10-28 Added battery voltage measurement and ZB Power Config Cluster
2023-10-28 Test battery voltage measurement
2023-10-29 Code cleanup. Separate battery function
2023-11-11 Wrong attribute value for battery
    [main.c]
2023-11-11 Adjusted Power Config cluster creation
2023-11-11 Cleaned up battery structure. Now reporting battery percentage
2023-11-24 Better filtering. 4H min report time. Report battery percentage if needed.
2024-07-03 Removed default factory button management. Fixed poll_interval bug
    [main.c]
2024-07-03 Changed Factory Reset button to BTN2
2024-07-03 Boost 3V TI doc
2024-07-03 Display message when compiling with 3V calibration
2024-07-04 Start of CAD work
    [E73-2G4M08S1C.step, SwiftSoilMoistureZigbeeSensor.kicad_pcb, SwiftSoilMoistureZigbeeSensor.kicad_sch]
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2024-07-04 Ignore KiCAD fp cache file
2024-07-04 Footprint associations
    [SwiftSoilMoistureZigbeeSensor.kicad_sch]
2024-07-07 Replaces BTN2 with BTN3
    [main.c]
2024-07-08 CAD Stuff
    [SwiftSoilMoistureZigbeeSensor.kicad_pcb, SwiftSoilMoistureZigbeeSensor.kicad_sch]
2024-07-08 LED and R1 sizes to 0603
    [SwiftSoilMoistureZigbeeSensor.kicad_pcb, SwiftSoilMoistureZigbeeSensor.kicad_sch]
2024-07-08 Comp Label renaming
    [SwiftSoilMoistureZigbeeSensor.kicad_pcb, SwiftSoilMoistureZigbeeSensor.kicad_sch]
2024-07-10 Calling power_down_unued_ram for sed version
2024-07-11 Ground planes
    [SwiftSoilMoistureZigbeeSensor.kicad_pcb]
2024-07-11 Relative project paths in Kicad files
2024-07-16 JLCPCB Kicad Fab settings
    [SwiftSoilMoistureZigbeeSensor.kicad_pcb]
2024-07-16 Ignore Kicad fab files
2024-07-23 Imported 3D model of the E73 module
    [SwiftSoilMoistureZigbeeSensor.kicad_pcb]
2024-07-27 Added LCSC refs
    [SwiftSoilMoistureZigbeeSensor.kicad_sch]
2024-07-28 Mark unconnected pins. Enlarged L1 connections
    [SwiftSoilMoistureZigbeeSensor.kicad_pcb, SwiftSoilMoistureZigbeeSensor.kicad_sch]
2024-07-28 Schematics of this project
2024-08-12 Changed SWD connector
    [SwiftSoilMoistureZigbeeSensor.kicad_pcb, SwiftSoilMoistureZigbeeSensor.kicad_sch]
2024-08-12 Rewworked SWD connector
    [SwiftSoilMoistureZigbeeSensor.kicad_pcb, SwiftSoilMoistureZigbeeSensor.kicad_sch]
2024-08-13 Bad LED wiring
    [SwiftSoilMoistureZigbeeSensor.kicad_pcb, SwiftSoilMoistureZigbeeSensor.kicad_sch]
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2024-08-13 1 sec probe power instead of 500ms
2024-08-13 Reverted LED state because of HW error
    [main.c]
2024-08-16 Force battery report as needed
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2024-08-18 Preserve probe power supply until value is ok
2024-08-19 Removed main low pass filter. Removed force_report arg for battery measurement
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2024-08-24 Suppressed turbo_poll that prevents many Data Request frames
    [main.c]
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2024-08-26 PCB Version 1.1
    [SwiftSoilMoistureZigbeeSensor.kicad_pcb, SwiftSoilMoistureZigbeeSensor.kicad_sch]
2024-08-26 Updated LCSC BOM
    [SwiftSoilMoistureZigbeeSensor.kicad_sch]
2024-08-27 Change LCSC part ref
    [SwiftSoilMoistureZigbeeSensor.kicad_sch]
2024-08-27 Low filter computation round error
    [main.c]
2024-08-28 Voltage low filter computation issue. Factory reset code moved.
    [main.c]
2024-08-31 Reworkd start up code. Set Long Poll to reasonable duration
    [main.c]
2024-09-10 680ohm is enough. SWD silk text for convinience
    [SwiftSoilMoistureZigbeeSensor.kicad_pcb, SwiftSoilMoistureZigbeeSensor.kicad_sch]
2024-09-16 Rewrote factory reset part
    [main.c]
2024-09-17 Inductance footprint modified. Probe print
    [SwiftSoilMoistureZigbeeSensor.kicad_pcb, SwiftSoilMoistureZigbeeSensor.kicad_sch]
2024-09-19 Added 3D models for L1 and SW1
    [B3FS-1010.STEP, NR3015T4R7M.stp, SwiftSoilMoistureZigbeeSensor.kicad_pcb]
2024-09-22 Colored button
    [B3FS-1010.STEP]
2024-09-22 Better coil model
    [NR3015T4R7M.stp]
2024-09-23 Schematics version update.
    [SwiftSoilMoistureZigbeeSensor.kicad_sch]
2024-10-01 Replaced Jumper with SB
    [SwiftSoilMoistureZigbeeSensor.kicad_pcb, SwiftSoilMoistureZigbeeSensor.kicad_sch]
2024-10-03 Invisible SWD header. New hardware illustration image
    [SwiftSoilMoistureZigbeeSensor.kicad_pcb]
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2024-10-05 Removed Jumper/SB
    [SwiftSoilMoistureZigbeeSensor.kicad_pcb, SwiftSoilMoistureZigbeeSensor.kicad_sch]
2024-10-08 Arranged cad stuff
    [B3FS-1010.STEP, E73-2G4M08S1C.step, NR3015T4R7M.stp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]
2024-10-08 3D box cad
    [box.FCStd, box.stl]
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2024-10-08 Updated BOX
    [box.FCStd, box.stl]
2024-10-13 Changed TPS61221 to TPS61097
    [SwiftSoilMoistureZigbeeSensor.kicad_pcb, SwiftSoilMoistureZigbeeSensor.kicad_sch]
2024-10-13 BOM update
    [SwiftSoilMoistureZigbeeSensor.kicad_sch]
2024-10-26 Enlarged box
    [box.FCStd, box.stl]
2024-11-03 Modified box. Slightly enlarged
    [box.FCStd, box.stl]
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2024-12-16 Grammar. Box and Lid CAD
    [box+lid.stl, box.FCStd, box.stl]
2024-12-22 Recentered lid hole
    [box.FCStd]
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2025-02-10 Modified lid in STL
    [box+lid.stl]
